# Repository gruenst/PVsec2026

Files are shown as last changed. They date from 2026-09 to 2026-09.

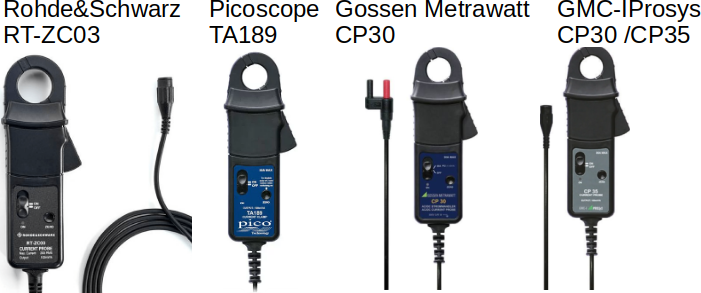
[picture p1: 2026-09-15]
02_CurrentClamp/ClampManufacturers.png

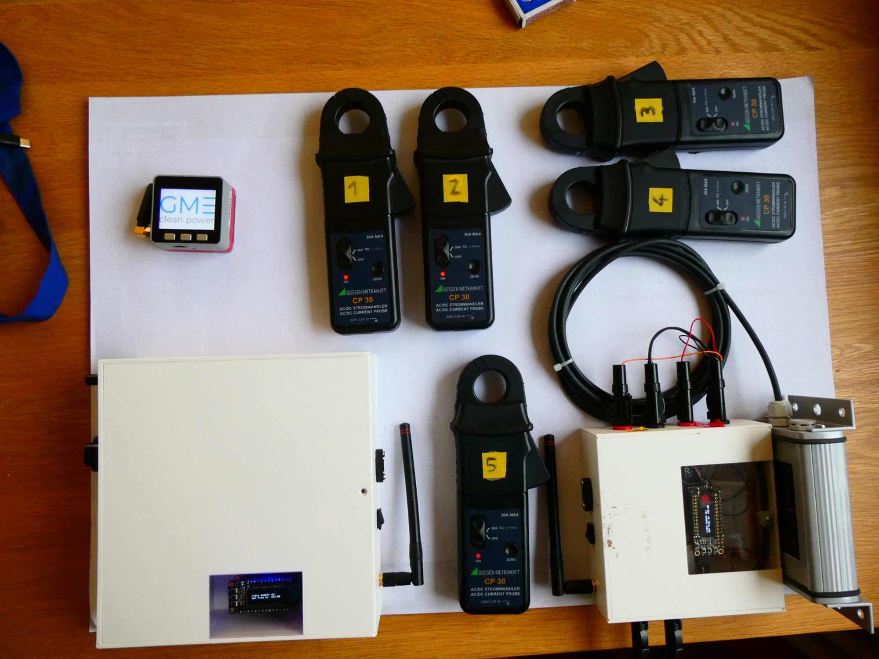
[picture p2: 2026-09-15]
03.JPG

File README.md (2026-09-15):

# Open Source Hardware for Mobile String Power Acquisition of Solar Parks
Circuitpython and C++ based measurement system for Photovoltaic Installations. Up to 10 current clamps can be integrated, additional voltage, current and module temperature acquisition.


## Purpose
 * Open-source enhancements of publicly available hardware resources with LoRa radio for long range sensor data acquisition capability (no mesh network).
 * Complete system for measuring solar parks with flawed or without string monitoring
 * Versatile alternative to IV curve acquisition systems specifically for systems without single string accessibility - adapt to your own liking.

## Usage
 * Plug device in, opens up as USB stick (circuitpython)
 * Open .html file in Web Serial API compatible browser (Chrome, Edge, Opera; see https://developer.mozilla.org/en-US/docs/Web/API/Serial)
 * Use browser as GUI, connect to device and send/receive commands to/from device via serial interface
 * commands will be forwarded via LoRa RFM98W radio chip to remote device
 
## Content
 - Descriptions:    Short descriptions of each system with pictures 
 - PCBs, BOM:       EAGLE Cad PCB files, list of components
 - Housing:         3D STP files for 3D printing
 - Circuit Python:  Circuitpython .uf2, device code
 - GUI:             code.py for device, .html code with .js elements for GUI control, Arduino C++ code, web Serial or WLAN websocket control
 - bootloader:      Atmel SAMD bootloader for JLink
[https://learn.adafruit.com/how-to-program-samd-bootloaders](https://learn.adafruit.com/how-to-program-samd-bootloaders)

## Manual
 - Make PCB, solder components
 - flash bootloader using .bin file, e.g. via JLink, see https://learn.adafruit.com/how-to-program-samd-bootloaders
 - mount device via usb, put into bootloader mode, upload circuitpython .uf2 file
 - copy circuitpython8 lib elements to /lib directory on device
 - put code.py to device
 - upload .html file to device, adjust accordingly
 enjoy!
 
[Grn.Solar](https://www.grn.solar)
 
 Big shoutouts to [Adafruit](https://www.adafruit.com "Adafruit rocks") and Flaticon.

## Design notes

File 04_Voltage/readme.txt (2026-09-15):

Lazy build for embedding a Phoenix Contact DC voltage level shifter (SCK-M-U-1500V) into a 3D printed case.
These components should be on the board:
 - 24V supply for the Phoenix Contact, power by 5V:  Murata NME0524DC
 - Adafruit ADS1115 breakout board
 - Adafruit PowerBoost 1000 Charger
 - Adafruit ItsyBitys M4 express
 
Embedding everything on a single PCB would be beneficial, but using an industry standard for 1500V string voltages seems reasonable.

DC connection via panel mount plugs (banana or solar connectors).
Power switch, with LED.
USB and SMA antenna plugs recommended.

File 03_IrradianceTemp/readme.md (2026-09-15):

# irradiance sensor with module temperature acquisition

Modification/hack of standard M&T irradiance sensors with an own-made PCB, and battery for independent operation.
As the current clamps, this is base don the Adafruit Itsybitsy M4 Express, so the code can be adapted/changed in the field with any computer (mounts as USB stick).
There is an USB B and C adapter for charging and programming.
There are soldering ports for adding a power switch, and adding an indicator LED. Alternatively, use a LED button.
PT temperature acquisition is done with a simple resistor bridge, as usually attachment of field sensors are by far the higher source of uncertainty than wire resistances.
But feel free to add a proper 4wire PT reading circuit (e.g. MAX31865), which was tested in yet another implementation.
As PT sensors, I recommend foil based ones with temperature conductive pastes. But whichever sensor, there is a lot to learn using them.

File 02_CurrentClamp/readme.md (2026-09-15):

# Current Clamp
resources for making a PCB for enhancing/hacking a commercially available DC current clamp (see type information) with LoRa and programming functionality. Here's a list of (probably identical) OEM products, only the third one has been used so far: ClampManufacturers

The board is based on the Adafruit "Itsybitsy M4 express" for Circuitpython, as this gives in-field programming capability (changing the current clamp number) with any USB computer. The PCB fits nicely underneath the existing PCB.
As an antenna, any flexible and solderable antenna for 433MHz works, also simple wire or spring antennas.
I recommend this one: https://ctrfantennasinc.com/flex-pcb-433mhz-lora-antenna/

Node numbers are 1-10 for the clamps, and 11-13 for the additional satellite systems (irradiance+temperature, voltage, repeater).

Instead of a standard 9V battery, a modified Li-based battery could be used and connected to the PCB for charging purpose.
Alternatively, add another battery or power bank for longer usage times.

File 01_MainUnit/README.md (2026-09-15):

# Main Unit
Either use an M5 Stack for control. Or use an USB LoRa adapter, plugged into your computer or smartphone.

- M5 Stack: can be controlled directly via buttons. Or via WLAN (webSocket) GUI.
- USB LoRa adapter:  dongle for LoRa communication, design based on Adafruit ItsyBitsy M4 Express. Can be controlled via USB (webSerial) or Android/iOS application (Flutter). Mounts as an USB stick with index.html accessible (Circuitpython).

NOTE:
M5 Stack fully works and was field tested.
USB LoRa adapter has not been tested. 
It's all there. But adaptations might be necessary.

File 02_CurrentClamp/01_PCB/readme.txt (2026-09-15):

EAGLE CAD files and BOM files for making current clamp modification PCB

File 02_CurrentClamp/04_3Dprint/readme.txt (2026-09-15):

3D printed case for replacing the entry cable hole of a Gossen Metrawatt CP30 current clamp with an USB connector
Originally designed for this connector:
https://www.adafruit.com/product/1829
..but really, anything works, if solderable..

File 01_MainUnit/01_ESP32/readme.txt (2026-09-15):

Easiest solution for the main unit:
The basic M5stack comes with an ESP32, display, SCcard slot and buttons.
https://shop.m5stack.com/products/esp32-basic-core-lot-development-kit-v2-7

In the meantime, there's also a LoRa 433MHz extension:
https://shop.m5stack.com/products/m5stack-lora-module-433mhz-v1-1
(adapt arduino code accordingly)

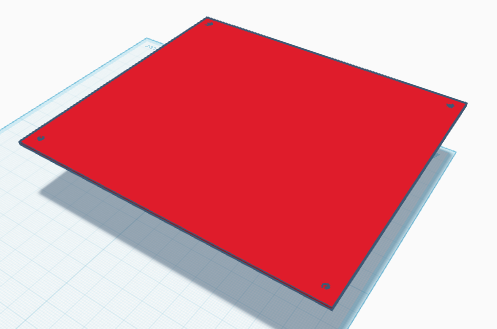
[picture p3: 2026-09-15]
04_Voltage/04_3Dprint/lid.png

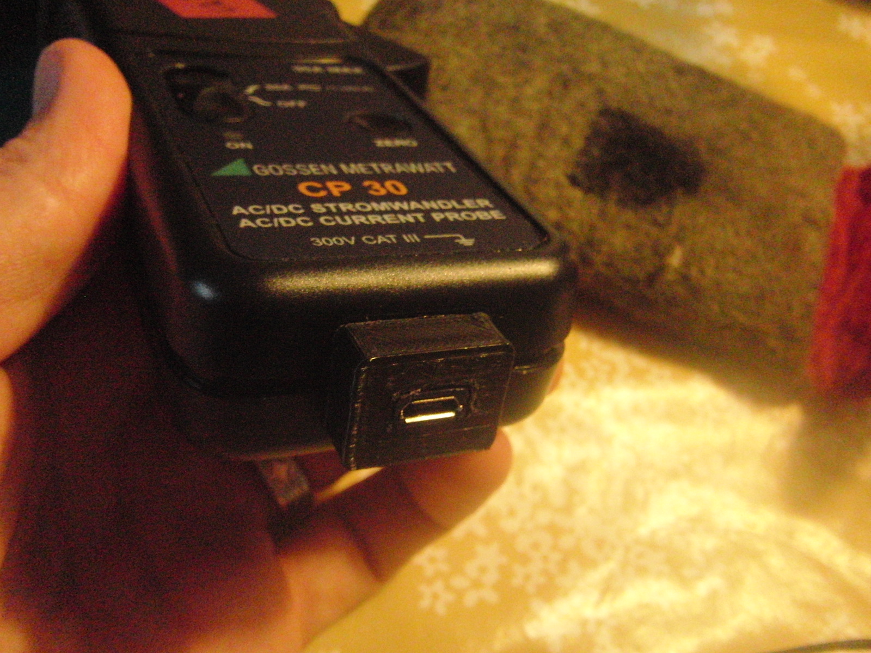
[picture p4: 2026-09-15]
02_CurrentClamp/05_images/CIMG1481.JPG

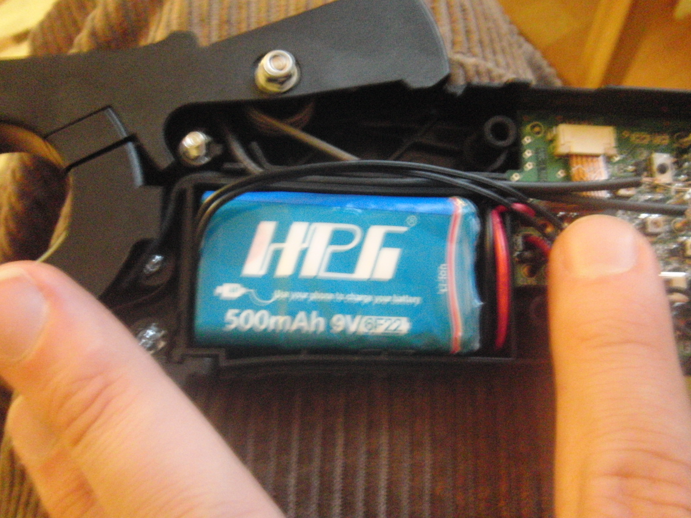
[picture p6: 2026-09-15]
02_CurrentClamp/05_images/CIMG1492.JPG

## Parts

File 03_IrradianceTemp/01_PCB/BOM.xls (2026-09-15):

Component | Description | size | form factor
C1 | 10.0µF, 0805 SMD Capacitor | 10uF | 805
C2 | 100.0nF, 0603 SMD Capacitor | 0.1uF | 603
C3 | 1.0µF, 0603 SMD Capacitor | 1uF | _0603MP
C4, C5, C7 | 1.0µF, 0603 SMD Capacitor | 1uF | 603
C6, C8, C10 | 10.0µF, 0805 SMD Capacitor | 10µF | 805
C9 | 10.0µF, 0805 SMD Capacitor | 10uF | _0805MP
D1 | MBR120AFC_R1_00001 https://www.panjit.com.tw/upload/datasheet/MBR18AFC_SERIES.pdfPANJIT | MBR120 | SOD123
FB1, FB2 | MMZ2012Y152BT000 https://product.tdk.com/en/system/files | MMZ2012Y152B | 805
IC2 | ATSAMD51G19A-MU https://www.mouser.com/datasheet/3/282/1/SAM_D5x_E5x_Family_Data_Sheet_DS60001507.pdfMicrochip | ATSAMD51G_TQFN48 | TQFN48_7MM
J1 | UJ2-MIBH-G-SMT-TR https://www.sameskydevices.com/product/resource/uj2-mibh-g-smt-tr.pdfSame Sky | UJ2-MIBH-G-SMT-TR | CUI_UJ2-MIBH-G-SMT-TR
L2 | 3341 Adafruit | RGB | APA102_2020
R1, R2, R5 | 10.0kΩ, 0805 SMD Resistor | 10K | 805
R3, R7 | 100.0kΩ, 0805 SMD Resistor | 100K | 805
R4 | 2.2kΩ, 0805 SMD Resistor | 2.2K | 805
R6 | 300.0Ω, 0805 SMD Resistor | 0.3K | 805
R8, R9 | 4.02kΩ, 0805 SMD, 1% Resistor | 4.02K | 805
R10 | 1.0kΩ, 0805 SMD Resistor | 1k | 805
R11 | 2.0kΩ, 0805 SMD Resistor | 2k | 805
R12, R13 | 5.1kΩ, 0805 SMD Resistor | 5.1K | 805
U1 | RFM98W-433S2 http://www.farnell.com/datasheets/1870822.pdfHoperf | RFM98-W | RFMHCW_SMT
U2 | INA219BIDCNT https://www.ti.com/lit/gpn/INA219Texas Instruments | INA219 | SOT23-8
U3 | AP2112K-3.3TRG1 https://www.diodes.com/assets/Datasheets/AP2112.pdfDiodes Inc. | AP2112K-3.3 | SOT23-5
U4 | GD25Q16CEIGR GigaDevice | GD25x16 | USON8
U5 | ADS1115IDGSR https://www.ti.com/lit/gpn/ADS1115Texas Instruments | ADS1115 | MSOP10
U6 | MCP73831T-2ACI/OT https://ww1.microchip.com/downloads/aemDocuments/documents/APID/ProductDocuments/DataSheets/MCP73831-Family-Data-Sheet-DS20001984H.pdfMicrochip | MCP73831T | SOT23-5
X1 | 1769 Adafruit | JSTPH | JSTPH2
X2 | 4458 Adafruit |  | USB_C_CUSB31-CFM2AX-01-X
U1 | HopeRF RFMHCW_SMT | RFM98-W

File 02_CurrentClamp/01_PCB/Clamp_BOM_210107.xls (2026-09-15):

Number | Manufacturer | Type | Package | description
1 | Texas Instruments | ADS1115 | VSSOP | 16bit ADC
1 | SHENZHEN LED COLOR | APA102 2020 | - | dotstar RGB LED
1 | Gigadevice | GD25Q16CEIGR | USON8 | SPI FLASH 8PIN
1 | HopeRF | RFM98W | RFMHCW_SMT | LoRa 433MHz
1 | Diodes Incorporated | AP2112K-3.3TRG1 | SOT23-5 | Voltage Regulator
2 | <any> | resistor 100k | 0805 | resistor 100k
2 | <any> | resistor 2.2k | 0805 | resistor 2.2k
3 | <any> | resistor 10k | 0805 | resistor 10k
2 | ON semiconductor | MBR120 | SOD-123FL | diode
1 | <any> | standard red LED SMD | 'CHIPLED 0603 | standard red LED SMD
1 | Microchip technology / atmel | ATSAMD51G19A | 48 QFN | SAM Microcontroller
2 | tdk | MMZ2012Y152B | 0805 | Ferrite Bead
4 | <any> | capacitor 10uF | 0805 | capacitor 10uF
4 | <any> | capacitor 1uF | 0603 | capacitor 1uF

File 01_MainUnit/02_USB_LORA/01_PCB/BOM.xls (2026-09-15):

Component | Description | size | form factor
C1 | 10.0µF, 0603 SMD Capacitor | 10uF | 0603@1
C2, C5, C7 | 1.0µF, 0603 SMD Capacitor | 1µF | 0603@1
C3, C4, C6 | 10.0µF, 0603 SMD Capacitor | 10µF | 0603@1
R1, R4 | 100.0kΩ, 0603 SMD Resistor | 100k | 603
R2, R3 | 5.1kΩ, 0603 SMD Resistor | 5.1k | 603
R6 | 10.0kΩ, 0805 SMD Resistor | 2.2K | 805
R7 | 10.0kΩ, 0805 SMD Resistor | 10K | 805
IC2 | ATSAMD51G19A-MU https://www.mouser.com/datasheet/3/282/1/SAM_D5x_E5x_Family_Data_Sheet_DS60001507.pdfMicrochip | ATSAMD51G_TQFN48 | TQFN48_7MM
L2 | 3341 Adafruit | RGB | APA102_2020
U3 | AP2112K-3.3TRG1 https://www.diodes.com/assets/Datasheets/AP2112.pdfDiodes Inc. | AP2112K-3.3 | SOT23-5
U4 | GD25Q16CEIGR GigaDevice | GD25x16 | USON8
USB_C | 4932 https://cdn-shop.adafruit.com/product-files/4932/Pinout+Diagram.pngAdafruit | USB_TYPE_C_12PUSB_TYPE_C_12P | USB_TYPE_C_12P
USB_C2 | 4458 Adafruit |  | USB_C_CUSB31-CFM2AX-01-X
U1 | HopeRF RFMHCW_SMT | RFM98-W

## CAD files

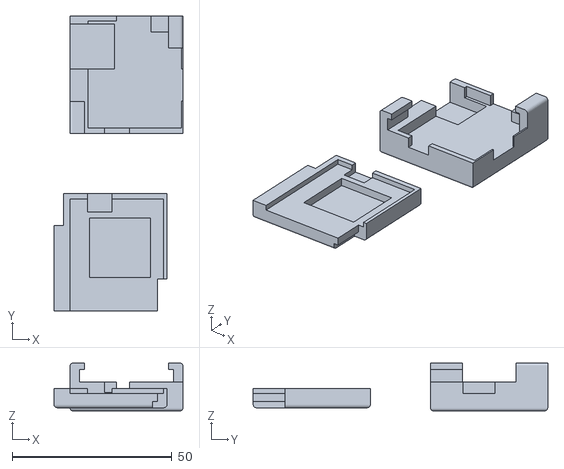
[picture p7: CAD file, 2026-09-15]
01_MainUnit/02_USB_LORA/04_3Dprint/USB_LoRa.stl
40.4 x 92.2 x 15.0

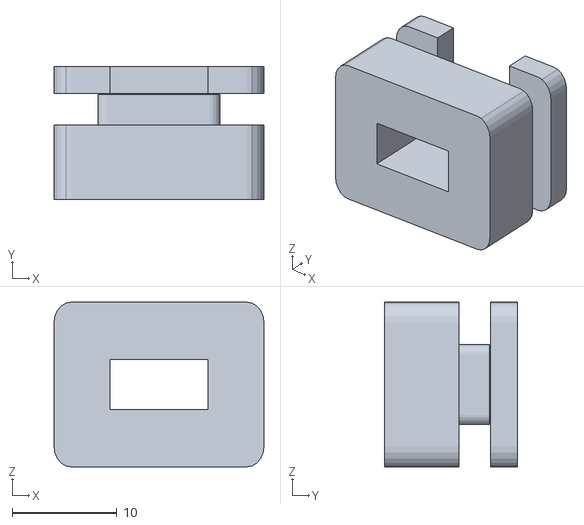
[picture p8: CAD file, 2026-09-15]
02_CurrentClamp/04_3Dprint/ClampHole_201114.stl
20.0 x 12.7 x 15.7

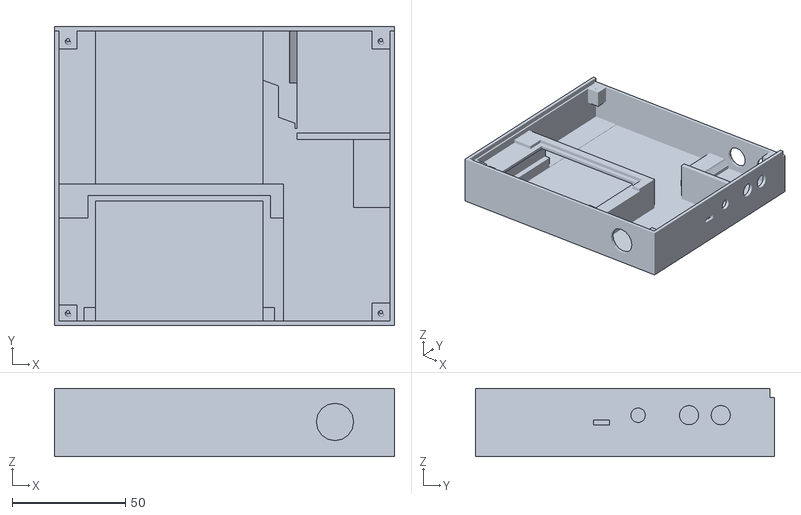
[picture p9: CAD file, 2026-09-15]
04_Voltage/04_3Dprint/box.stl
150.0 x 132.0 x 30.0

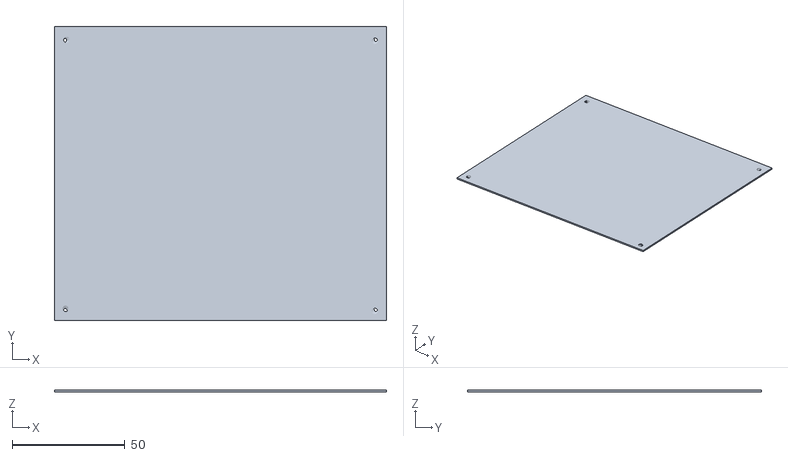
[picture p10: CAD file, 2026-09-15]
04_Voltage/04_3Dprint/lid.stl
147.5 x 130.7 x 0.9

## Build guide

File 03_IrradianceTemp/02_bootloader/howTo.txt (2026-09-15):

 After printing PCB:
 1) flash a basic bootloader on PCB using JLINK hardware, steps:
  - connect JLINK to PC and pins to PCB (1-voltage, 2-gnd, -1-IO -2-clk)
  - power PCB (Vref) with another arduino or DC voltage source
  - use command line from folder with .bin file
  - flash bootloader by executing software "JLinkExe"
  - select JLinkExe-options ('connect' -> ATSAMD51G19A - SWD -> default)
  - execute command 'loadbin Clamp_bootloader_260901.bin,0'
  - select JLinkExe-options ('r' -> 'g')
 2) get CircuitPython for "ItsyBitsy M4 Express", upload .uf2 to board
 https://circuitpython.org/board/itsybitsy_m4_express/
 3) upload circuitpython library bundle
 https://circuitpython.org/libraries
 4) upload code.py
 ...and modify to your own liking...

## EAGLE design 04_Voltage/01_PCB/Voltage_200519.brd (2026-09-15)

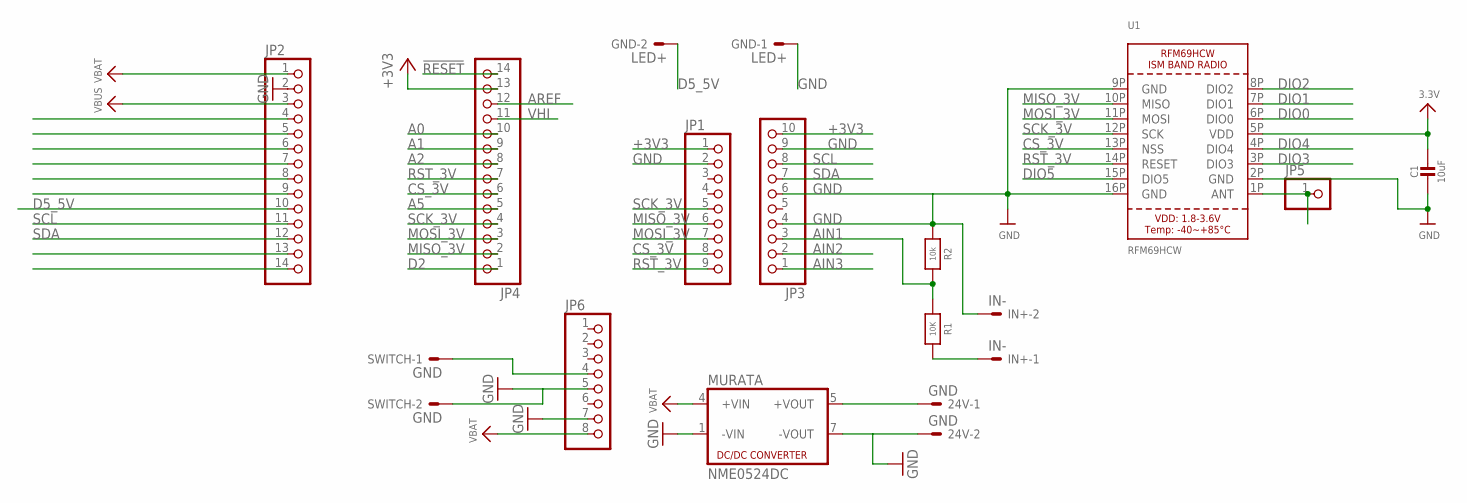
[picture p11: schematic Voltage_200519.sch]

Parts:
24V: GND; 332-02
C1: 10uF; 0805-NO@1
GND: LED+; 332-02
IN+: IN-; 332-02
JP1: HEADER-1X970MIL; 1X09_ROUND_70
JP2, JP4: HEADER-1X14; 1X14_ROUND70
JP3: HEADER-1X1070MIL; 1X10_ROUND70
JP5: HEADER-1X1ROUND; 1X01_ROUND
JP6: HEADER-1X8ROUND; 1X08_ROUND
MURATA: NME0524DC; 8DIL-4
R1: 10K; 0805-NO
R2: 10k; 0805-NO
SWITCH: GND; 332-02
U1: RFM69HCW; RFMHCW_SMT

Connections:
!RESET: JP4.14
+3V3: C1.1, JP1.1, JP3.10, JP4.13, U1.5P (VDD)
A0: JP4.10
A1: JP4.9
A2: JP4.8
A5: JP4.5
AIN1: JP3.3, R1.1, R2.2
AIN2: JP3.2
AIN3: JP3.1
AREF: JP4.12
CS_3V: JP1.8, JP4.6, U1.13P (NSS)
D2: JP4.1
D5_5V: GND.2, JP2.10
D7: JP2.9
D9: JP2.8
D10: JP2.7
D11: JP2.6
D12: JP2.5
D13: JP2.4
DIO0: U1.6P (DIO0)
DIO1: U1.7P (DIO1)
DIO2: U1.8P (DIO2)
DIO3: U1.3P (DIO3)
DIO4: U1.4P (DIO4)
DIO5: U1.15P (DIO5)
GND: 24V.2, C1.2, GND.1, IN+.2, JP1.2, JP2.2, JP3.4, JP3.6, JP3.9, JP6.5, JP6.7, MURATA.1 (-VIN), MURATA.7 (-VOUT), R2.1, SWITCH.2, U1.2P (GND), U1.9P (GND), U1.16P (GND)
MISO_3V: JP1.6, JP4.2, U1.10P (MISO)
MOSI_3V: JP1.7, JP4.3, U1.11P (MOSI)
unnamed: JP5.1, U1.1P (ANT)
unnamed: JP6.4, SWITCH.1
unnamed: IN+.1, R1.2
unnamed: 24V.1, MURATA.5 (+VOUT)
RST_3V: JP1.9, JP4.7, U1.14P (RESET)
RX_D0: JP2.14
SCK_3V: JP1.5, JP4.4, U1.12P (SCK)
SCL: JP2.11, JP3.8
SDA: JP2.12, JP3.7
TX_D1: JP2.13
VBAT: JP2.1, JP6.8, MURATA.4 (+VIN)
VBUS: JP2.3
VHI: JP4.11

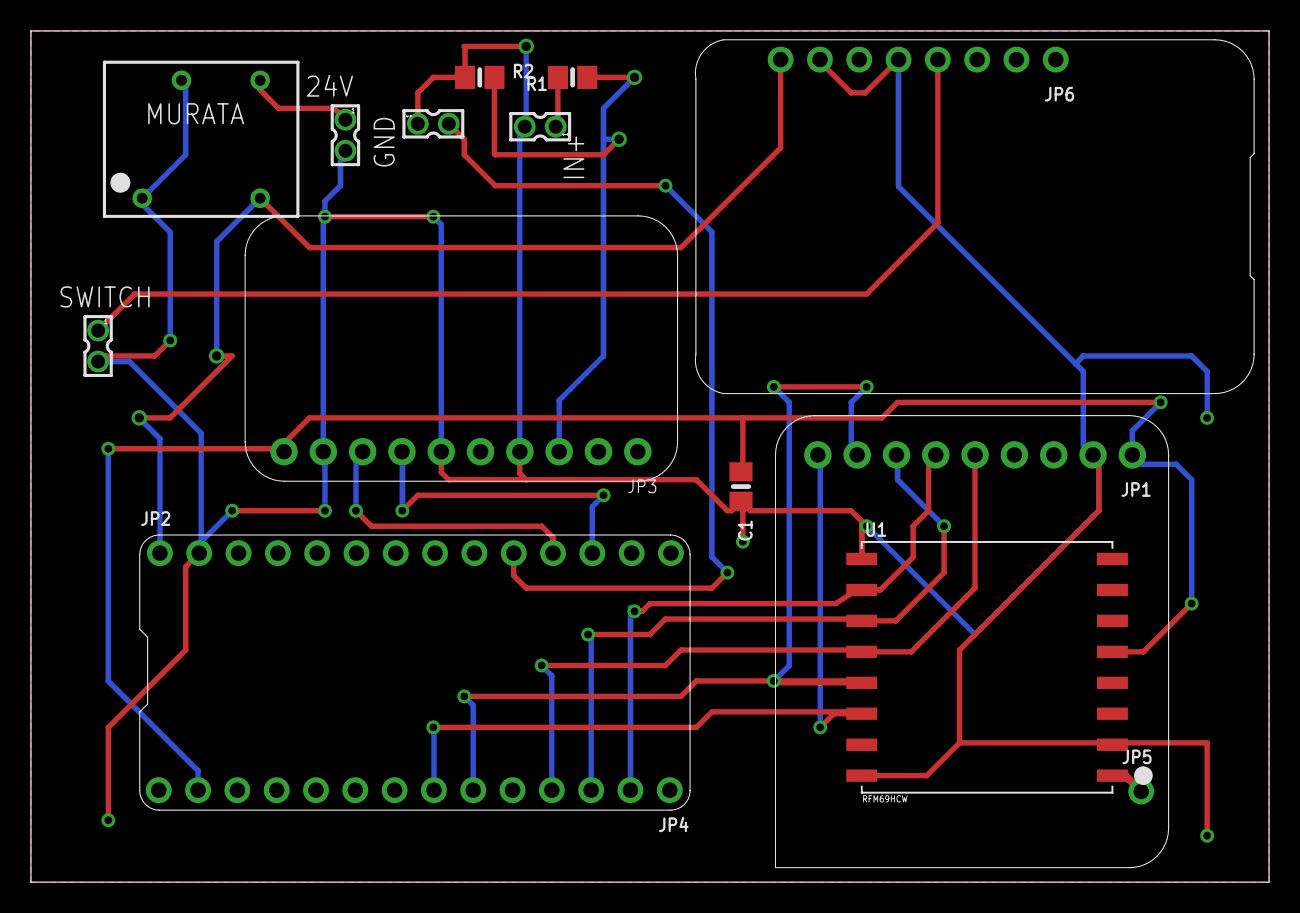
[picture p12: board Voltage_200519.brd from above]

Board: 2 copper layers, 80.0 x 55.0 mm, 15 parts (0 on the bottom side), 16 nets.

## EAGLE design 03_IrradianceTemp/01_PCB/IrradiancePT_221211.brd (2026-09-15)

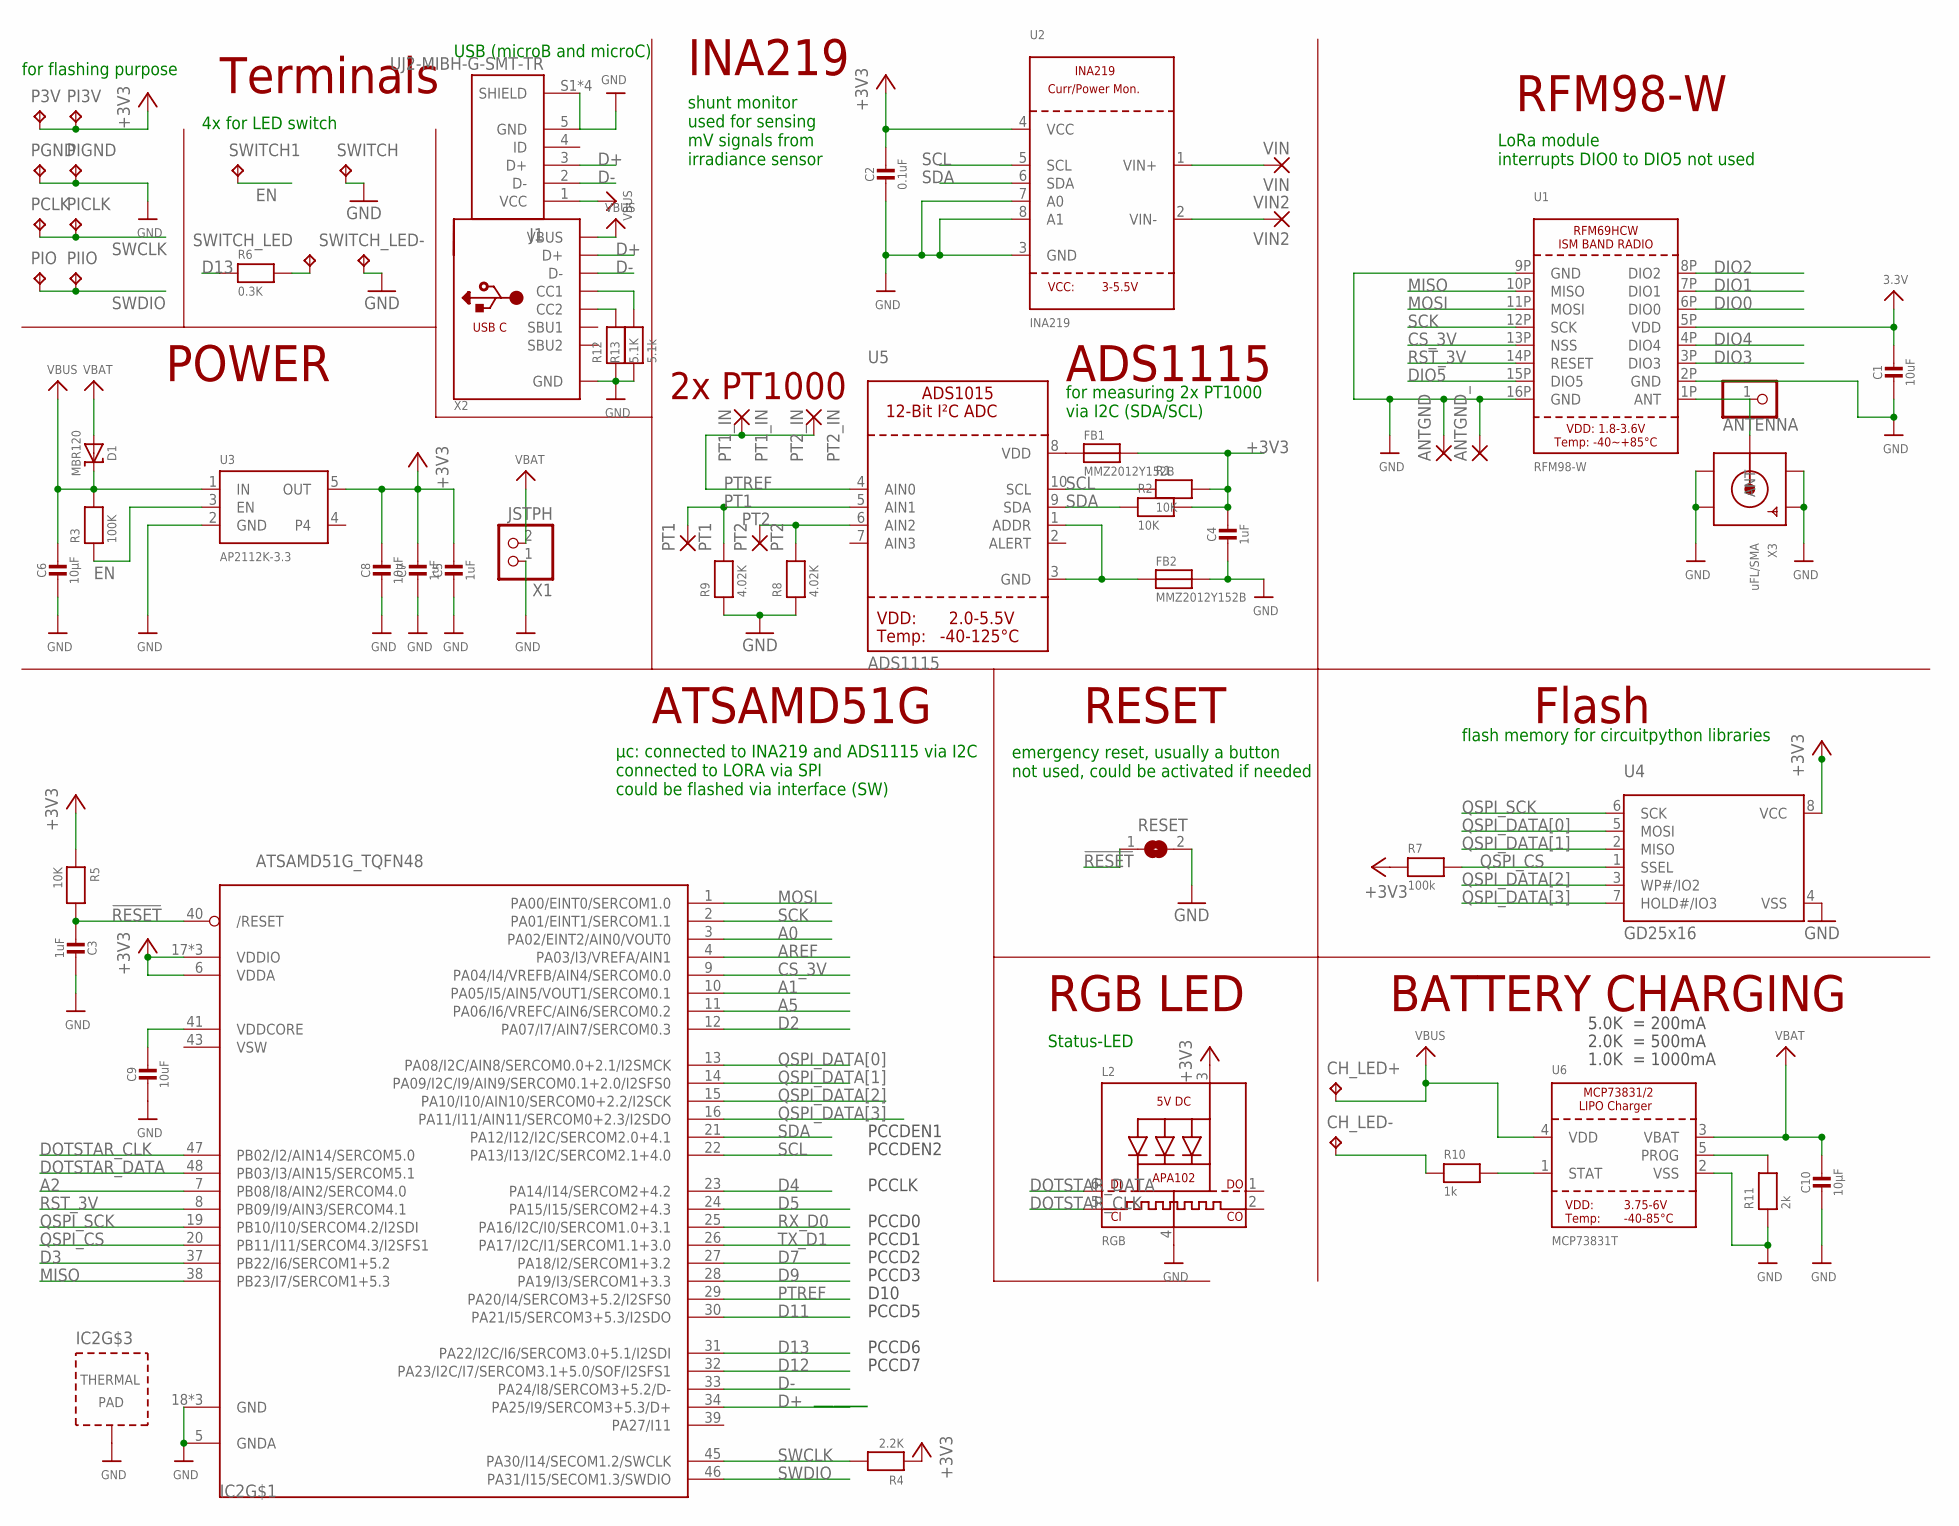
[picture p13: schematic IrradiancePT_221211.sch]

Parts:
ANTENNA: HEADER-1X1ROUND; 1X01_ROUND
ANTGND: SMD5; SMD2,54-5,08
ANTGND_: SMD5; SMD2,54-5,08
C1: 10uF; 0805-NO
C2: 0.1uF; 0603-NO
C3: 1uF; _0603MP
C4, C5, C7: 1uF; 0603-NO
C6, C8, C10: 10µF; 0805-NO
C9: 10uF; _0805MP
CH_LED+: TPPAD1-13; P1-13
CH_LED-: TPPAD1-13; P1-13
D1: MBR120; SOD-123
FB1, FB2: MMZ2012Y152B; 0805
IC2: ATSAMD51G_TQFN48; TQFN48_7MM
J1: UJ2-MIBH-G-SMT-TR; CUI_UJ2-MIBH-G-SMT-TR
L2: RGB; APA102_2020
P3V: TPTP20R; TP20R
PCLK: TPTP20R; TP20R
PGND: TPTP20R; TP20R
PI3V: TPPAD1-13; P1-13
PICLK: TPPAD1-13; P1-13
PIGND: TPPAD1-13; P1-13
PIIO: TPPAD1-13; P1-13
PIO: TP20R
PT1: PT1; 1,6/0,9
PT1_IN: PT1_IN; 1,6/0,9
PT2: PT2; 1,6/0,9
PT2_IN: PT2_IN; 1,6/0,9
R1, R2, R5: 10K; 0805
R3: 100K; 0805
R4: 2.2K; 0805
R6: 0.3K; 0805
R7: 100k; 0805
R8, R9: 4.02K; 0805
R10: 1k; 0805
R11: 2k; 0805
R12: 5.1K; 0805
R13: 5.1k; 0805
RESET: SOLDERJUMPER; SOLDERJUMPER_ARROW_NOPASTE
SWITCH, SWITCH1: TPPAD1-13; P1-13
SWITCH_LED: TPPAD1-13; P1-13
SWITCH_LED-: TPPAD1-13; P1-13
U1: RFM98-W; RFMHCW_SMT
U2: INA219; SOT23-8
U3: AP2112K-3.3; SOT23-5
U4: GD25x16; USON8
U5: ADS1115; MSOP10
U6: MCP73831T; SOT23-5
VIN: VIN; 1,6/0,9
VIN2: VIN2; 1,6/0,9
X1: JSTPH; JSTPH2
X2: USB_C; USB_C_CUSB31-CFM2AX-01-X
X3: uFL/SMA; SMA_EDGELAUNCH_UFL

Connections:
!RESET: C3.2, IC2.40 (/RESET), R5.2, RESET.1
+3V3: C1.1, C2.1, C4.1, C5.1, C7.1, C8.1, FB1.2, IC2.6 (VDDA), IC2.17 (VDDIO), IC2.36 (VDDIO), IC2.44 (VDDIO), L2.3 (VDD), P3V.TP, PI3V.TP, R1.2, R2.2, R4.1, R5.1, R7.1, U1.5P (VDD), U2.4 (VCC), U3.5 (OUT), U4.8 (VCC)
A0: IC2.3 (PA02/EINT2/AIN0/VOUT0)
A1: IC2.10 (PA05/I5/AIN5/VOUT1/SERCOM0.1)
A2: IC2.7 (PB08/I8/AIN2/SERCOM4.0)
A5: IC2.11 (PA06/I6/VREFC/AIN6/SERCOM0.2)
AREF: IC2.4 (PA03/I3/VREFA/AIN1)
CS_3V: IC2.9 (PA04/I4/VREFB/AIN4/SERCOM0.0), U1.13P (NSS)
D2: IC2.12 (PA07/I7/AIN7/SERCOM0.3)
D3: IC2.37 (PB22/I6/SERCOM1+5.2)
D4: IC2.23 (PA14/I14/SERCOM2+4.2)
D5: IC2.24 (PA15/I15/SERCOM2+4.3)
D7: IC2.27 (PA18/I2/SERCOM1+3.2)
D9: IC2.28 (PA19/I3/SERCOM1+3.3)
D11: IC2.30 (PA21/I5/SERCOM3+5.3/I2SDO)
D12: IC2.32 (PA23/I2C/I7/SERCOM3.1+5.0/SOF/I2SFS1)
D13: IC2.31 (PA22/I2C/I6/SERCOM3.0+5.1/I2SDI), R6.1
D+: IC2.34 (PA25/I9/SERCOM3+5.3/D+), J1.3 (D+), X2.A6 (D+), X2.B6 (D+)
D-: IC2.33 (PA24/I8/SERCOM3+5.2/D-), J1.2 (D-), X2.A7 (D-), X2.B7 (D-)
DIO0: U1.6P (DIO0)
DIO1: U1.7P (DIO1)
DIO2: U1.8P (DIO2)
DIO3: U1.3P (DIO3)
DIO4: U1.4P (DIO4)
DIO5: U1.15P (DIO5)
DOTSTAR_CLK: IC2.47 (PB02/I2/AIN14/SERCOM5.0), L2.5 (CKI)
DOTSTAR_DATA: IC2.48 (PB03/I3/AIN15/SERCOM5.1), L2.6 (DI)
EN: R3.1, SWITCH1.TP, U3.3 (EN)
GND: ANTGND.1, ANTGND_.1, C1.2, C2.2, C3.1, C4.2, C5.2, C6.2, C7.2, C8.2, C9.2, C10.2, FB2.2, IC2.5 (GNDA), IC2.18 (GND), IC2.35 (GND), IC2.42 (GND), IC2.THERMAL (TP), J1.5 (GND), J1.S1 (SHIELD), J1.S2 (SHIELD), J1.S3 (SHIELD), J1.S4 (SHIELD), L2.4 (GND), PGND.TP, PIGND.TP, R8.1, R9.1, R11.1, R12.1, R13.1, RESET.2, SWITCH.TP, SWITCH_LED-.TP, U1.2P (GND), U1.9P (GND), U1.16P (GND), U2.3 (GND), U2.7 (A0), U2.8 (A1), U3.2 (GND), U4.4 (VSS), U6.2 (VSS), X1.1, X2.A1B12 (GND), X2.B1A12 (GND), X3.GND@1 (GND1), X3.GND@2 (GND2), X3.GND@3 (GND3), X3.GND@4 (GND4)
GND_IN: FB2.1, U5.1 (ADDR), U5.3 (GND)
MISO: IC2.38 (PB23/I7/SERCOM1+5.3), U1.10P (MISO)
MOSI: IC2.1 (PA00/EINT0/SERCOM1.0), U1.11P (MOSI)
unnamed: ANTENNA.1, U1.1P (ANT), X3.P (ANT)
unnamed: R6.2, SWITCH_LED.TP
unnamed: U2.1 (VIN+), VIN.1
unnamed: U2.2 (VIN-), VIN2.1
unnamed: FB1.1, U5.8 (VDD)
unnamed: CH_LED-.TP, R10.1
unnamed: R10.2, U6.1 (STAT)
unnamed: R11.2, U6.5 (PROG)
unnamed: R13.2, X2.A5 (CC1)
unnamed: R12.2, X2.B5 (CC2)
PT1: PT1.1, R9.2, U5.5 (AIN1)
PT2: PT2.1, R8.2, U5.6 (AIN2)
PTREF: IC2.29 (PA20/I4/SERCOM3+5.2/I2SFS0), PT1_IN.1, PT2_IN.1, U5.4 (AIN0)
QSPI_CS: IC2.20 (PB11/I11/SERCOM4.3/I2SFS1), R7.2, U4.1 (SSEL)
QSPI_DATA[0]: IC2.13 (PA08/I2C/AIN8/SERCOM0.0+2.1/I2SMCK), U4.5 (MOSI)
QSPI_DATA[1]: IC2.14 (PA09/I2C/I9/AIN9/SERCOM0.1+2.0/I2SFS0), U4.2 (MISO)
QSPI_DATA[2]: IC2.15 (PA10/I10/AIN10/SERCOM0+2.2/I2SCK), U4.3 (WP#/IO2)
QSPI_DATA[3]: IC2.16 (PA11/I11/AIN11/SERCOM0+2.3/I2SDO), U4.7 (HOLD#/IO3)
QSPI_SCK: IC2.19 (PB10/I10/SERCOM4.2/I2SDI), U4.6 (SCK)
RST_3V: IC2.8 (PB09/I9/AIN3/SERCOM4.1), U1.14P (RESET)
RX_D0: IC2.25 (PA16/I2C/I0/SERCOM1.0+3.1)
SCK: IC2.2 (PA01/EINT1/SERCOM1.1), U1.12P (SCK)
SCL: IC2.22 (PA13/I13/I2C/SERCOM2.1+4.0), R1.1, U2.5 (SCL), U5.10 (SCL)
SDA: IC2.21 (PA12/I12/I2C/SERCOM2.0+4.1), R2.1, U2.6 (SDA), U5.9 (SDA)
SWCLK: IC2.45 (PA30/I14/SECOM1.2/SWCLK), PCLK.TP, PICLK.TP, R4.2
SWDIO: IC2.46 (PA31/I15/SECOM1.3/SWDIO), PIIO.TP, PIO.TP
TX_D1: IC2.26 (PA17/I2C/I1/SERCOM1.1+3.0)
VBAT: C10.1, D1.A, U6.3 (VBAT), X1.2
VBUS: C6.1, CH_LED+.TP, D1.C, J1.1 (VCC), R3.2, U3.1 (IN), U6.4 (VDD), X2.A4B9 (VBUS), X2.B4A9 (VBUS)
VDDCORE: C9.1, IC2.41 (VDDCORE)
VSW: IC2.43 (VSW)

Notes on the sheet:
Terminals
RFM98-W
INA219
POWER
RESET
µc: connected to INA219 and ADS1115 via I2C connected to LORA via SPI could be flashed via interface (SW)
PCCDEN1
PCCDEN2
PCCD0
PCCD1
PCCD2
PCCD3
D10
PCCD5
PCCD6
PCCD7
PCCLK
Flash
RGB LED
ATSAMD51G
LoRa module interrupts DIO0 to DIO5 not used
shunt monitor used for sensing mV signals from irradiance sensor
emergency reset, usually a button not used, could be activated if needed
flash memory for circuitpython libraries
ADS1115
2x PT1000
Status-LED
for flashing purpose
USB (microB and microC)
for measuring 2x PT1000 via I2C (SDA/SCL)
5.0K = 200mA
2.0K = 500mA
1.0K = 1000mA
BATTERY CHARGING
4x for LED switch

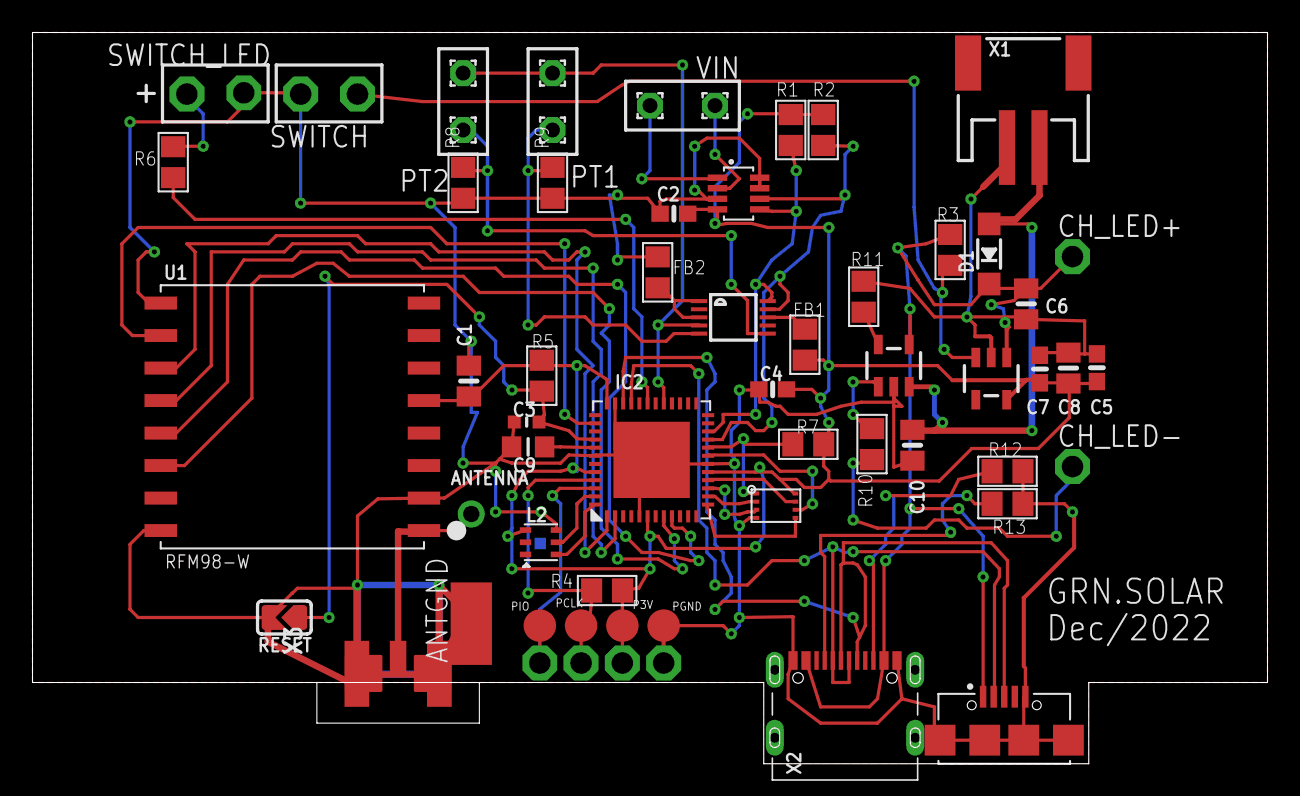
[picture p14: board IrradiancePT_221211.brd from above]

Board: 2 copper layers, 76.0 x 45.0 mm, 62 parts (1 on the bottom side), 41 nets.

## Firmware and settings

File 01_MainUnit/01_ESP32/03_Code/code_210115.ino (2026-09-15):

// Main Unit: receive measured data from satellite devices, central node point
// consists of: microcontroller (M5stack), LoRa Radio card (RFM96), RealTime Clock (DS1307)
// The M5stack contains: LiPo battery charging, microSD Card slot, WiFi interface, TFT display and 3 buttons
// function: 2 buttons for entering identifier; one button for measurement (2nd press stores data on SD card)
//           pressing the measurement button will trigger radio signal "measure" being sent; data will then be collected
//           from every satellite device individually
// The M5stack opens up a webserver at startup; when connecting via WiFi, data can be sent both way via the websocket; simply open IP in browser.
// Code Structure:  <libraries/definitions>  <setup>  <code loop>

//----------- Libraries -------------------------------------
#include <SPI.h>
//#include <RHGenericSPI.h>
//#include <RH_RF95.h>
#include <M5LoRa.h>
#include <Wire.h>
#include <SD.h>  //not needed with M5?
#include <M5Stack.h>
#include <WiFi.h>
#include <ESPAsyncWebServer.h>
#include <SPIFFS.h>
#include "RTClib.h"
//--------END Libraries -------------------------------------

//-----------PIN definitions---------------------------------
#define RFM95_CS 5       // LoRa Chip Select
#define RFM95_RST 35     // LoRa Reset pin   //36 on first M5!!!
#define RFM95_INT 26     // LoRa Interrupt pin
//-------END PIN definitions---------------------------------

//-------Global variables, drivers and definitions -----------
#define RF95_FREQ 433E6  //LoRa frequency
#define NUM_SATELLITES 13   // number of satellite devices, followed by the keywords for each one
String satellites[NUM_SATELLITES] = {"clamp_1", "clamp_2", "clamp_3", "clamp_4", "clamp_5","clamp_6", "clamp_7", "clamp_8", "clamp_9", "clamp_0", "irr_1", "volt_1","irr_2"};
//String satellites[NUM_SATELLITES] = {"clamp_1", "clamp_2", "clamp_3", "clamp_4", "irr_1", "volt_1","irr_2"};
String answers[NUM_SATELLITES]; // the answer strings with the measurement variables will be stored here
uint8_t Cursor = 0;             // cursor position
uint8_t NumClamps = 5;             // Number of Clamps 
uint64_t TriggerTime = 0;
String StringList = "-0123456789ABCDEFGHI";  // allowed characters for button character cycling
String StringID = "A-B-C-10-2";  //global var for string identifier
bool Saved = false;         // prevents from saving the same result multiple times   
bool FirstTime = true;   // writing the header to the SD card is only done once at the first SAVE operation
bool TftReset = true;       // TFT is cleared after measurement, not when changing string characters
bool ClampsOnly = false;
const char* SSID = "MAIN"; 
const char* PASSWORD = "testpass";
bool TriggerMeasure = false;      // measurement triggered from WLAN interface instead of button press
bool TriggerSave = false;        // save to file triggered from WLAN interface instead of button press
bool SaveToFile = false;       // choose to actually save to file
DateTime Now;          // time object
RTC_DS1307 rtc;        // real time clock
File MyFile;                // SD card file name
//---END Global variables, drivers and definitions -----------


//-------- Webserver and Websocket --------------------------
AsyncWebServer server(80);       // async web server on port 80
AsyncWebSocket ws("/ws");        // web socket is attached to server
AsyncWebSocketClient * GlobalClient = NULL;   // global client variable
// interrupt definitions for the websocket: gets activated by client
void onWsEvent(AsyncWebSocket * server, AsyncWebSocketClient * client, AwsEventType type, void * arg, uint8_t *data, size_t len){
  if(type == WS_EVT_CONNECT) GlobalClient = client; 
  else if(type == WS_EVT_DISCONNECT) GlobalClient = NULL;
  else if(type == WS_EVT_DATA)   // if a message from the client is received (MEASURE, CLAMPS, SAVE, TIME, or DATA)
  {
    String message = "";
    for(int i=0; i < len; i++)  message += char(data[i]);  // convert input characters to message-string
    if ((message.indexOf("MEASURE_") > -1) or (message.indexOf("CLAMPS_") > -1))    // used for starting the measurement
    {  TriggerMeasure = true;  SaveToFile = false;   // also aborts the data before saving
       if (message.indexOf("CLAMPS_") > -1) ClampsOnly  = true;
       else ClampsOnly = false;
       NumClamps = message[message.indexOf("_") + 1] - '0';  // simple convert character to integer
       if (NumClamps == 0) NumClamps = 10;   //  0 stands for 10
       StringID = message.substring(message.indexOf(';')+1,message.length());}   // read out string ID after ';'     
    else if (message.indexOf("SAVE") > -1) {  TriggerSave = true; SaveToFile = true; // save data to SD card
       StringID = message.substring(message.indexOf(';')+1,message.length());}
       
    else if (message.indexOf("TIME") > -1) {    // receive time string from websocket client
      message = message.substring(message.indexOf(';')+1,message.length());  
      M5.Lcd.println();M5.Lcd.println("time set");
      uint8_t dtDay, dtMonth, dtYear, dtHour, dtMinute;
      dtDay = message.substring(0,3).toInt();   
      dtMonth = message.substring(3,5).toInt(); 
      dtYear = message.substring(6,8).toInt();
      dtHour = message.substring(9,11).toInt();
      dtMinute = message.substring(12,14).toInt();
      rtc.adjust(DateTime(dtYear, dtMonth, dtDay, dtHour, dtMinute, 0));
      delay(500); 
      TftReset=true; 
    }
    else if (message.indexOf("DATA") > -1) {     // triggers all saved data from SD card being transferred back
      if (SD.exists("/AA_log.txt")) {
        MyFile = SD.open("/AA_log.txt", FILE_READ);
        String textLine = "DATA";
        if(GlobalClient != NULL && GlobalClient->status() == WS_CONNECTED)   //send file content via websocket
        {     
          while (MyFile.available())
          {
            char c = MyFile.read();
            textLine += c;
            if (c == '\n') {
              if (GlobalClient != NULL && GlobalClient->status() == WS_CONNECTED) GlobalClient->text(textLine);
              textLine = "DATA";
            }
          }
        }
        MyFile.close();
      }
    }
  }
}
//-------- END Webserver and Websocket --------------------------



void setup()    // initialize components, startup screen with logo
{
  //start M5stack without SD-Card and Serial;  SD-card is initialized further below
  M5.begin(true,false,false,true);   // LCD and I2C enable
  M5.Power.begin();  //start power management with charging
  //*****STARTUP SCREEN TEST, tests all components; halts if LoRa is not working
  M5.Lcd.fillScreen(TFT_BLACK);
  M5.Lcd.setRotation(1);
  M5.Lcd.setCursor(0, 0);
  M5.Lcd.setTextColor(TFT_WHITE);
  M5.Lcd.setTextSize(2);
  M5.Lcd.println("TFT:    OK");  // "if you see this, it works"
  
  M5.Lcd.print("Time: ");
  if (! rtc.begin())  M5.Lcd.println("failed");
  if (! rtc.isrunning())  rtc.adjust(DateTime(F(__DATE__), F(__TIME__)));   // adjust time when compiling code
  if (rtc.begin()) 
  { 
    Now = rtc.now();
    char tempString[20];
    sprintf(tempString, "%02d.%02d.%04d %02d:%02d", Now.day(), Now.month(), Now.year(), Now.hour(), Now.minute());
    M5.Lcd.println(tempString);
  } 
  //LoRa radio initialization
  LoRa.setPins(RFM95_CS, RFM95_RST, RFM95_INT);
  LoRa.setSpreadingFactor(9);
  LoRa.setSignalBandwidth(625E2);
  LoRa.setCodingRate4(8);
  LoRa.enableCrc();
  LoRa.setSPIFrequency(1E6);
  LoRa.setPreambleLength(8);
  //LoRa.setSyncWord(0x12);
  LoRa.setTxPower(23);
  //digitalWrite(RFM95_RST, LOW); delay(100); digitalWrite(RFM95_RST, HIGH); delay(5); // manual reset of LoRa chip
  M5.Lcd.print("Radio: ");
  if (!LoRa.begin(RF95_FREQ)) { M5.Lcd.println("failed"); while (1);  }  // HALTS if LoRa fails
  M5.Lcd.println("OK");
  LoRa.setSpreadingFactor(9);
  LoRa.setSignalBandwidth(625E2);
  LoRa.setCodingRate4(8);
  LoRa.enableCrc();
  LoRa.setSPIFrequency(1E6);
  LoRa.setPreambleLength(8);
  LoRa.setSyncWord(0x12);
  LoRa.setTxPower(23);
  M5.Lcd.print("frequ. ");
  M5.Lcd.print(RF95_FREQ/1000000,0);M5.Lcd.println("MHz");
  // SPIFFS initialization
  M5.Lcd.print("SPIFFS: ");
  if (!SPIFFS.begin(true)) M5.Lcd.println(" failed");
  else M5.Lcd.println("OK");
  // WiFi server initialization; async web server with web socket for two-way communication
  WiFi.softAP(SSID, PASSWORD);
  M5.Lcd.print("IP Adresse: ");
  M5.Lcd.println(WiFi.softAPIP());
  ws.onEvent(onWsEvent);
  server.addHandler(&ws);
  server.on("/", HTTP_GET, [](AsyncWebServerRequest* request) { request->send(SPIFFS, "/index.html");  } );
  server.begin();
  /*
  rf95.setTxPower(23, false);  //setIP LoRa radio boost to 23dB / 20dB(M5)
  rf95.setSignalBandwidth(125000);
  rf95.setCodingRate4(8);
  rf95.setPayloadCRC(true);
  */
  //begin SD card 
  M5.Lcd.print("SD card:  ");
  if (!SD.begin(4)) M5.Lcd.println("failed");
  else M5.Lcd.println("OK");
  delay(2000);
  //*****end startup screen
  //Startup Logo
  if (SD.exists("/logoTFT.png")) {M5.Lcd.drawPngFile(SD, "/logoTFT.png");
  delay(1500);}    // logo shown for 1.5 second
  //if possible get string name from TXT file  
  if (SD.exists("/string.txt"))
  {
    MyFile = SD.open("/string.txt");
    if (MyFile)
    {
      StringID = "";
      while (MyFile.available())
      {
        char x = MyFile.read();
        if (isGraph(x)) StringID.concat(x);  //only valid characters which make sense
      }
      MyFile.close();
    }
  }
  M5.update();
  delay(1000);
}


void loop()
{
  //********* BUTTON A AND B: CHANGE STRING IDENTIFIER
  if (TftReset == true)  // usually only renew characters without screen clearance
  {
    M5.Lcd.fillScreen(TFT_BLACK);M5.update();
    TftReset = false;
  }
  if (M5.BtnA.isPressed()) {
    if (Cursor == StringID.length() - 1) Cursor = 0;
    else Cursor += 1;
  }
  if (M5.BtnB.isPressed()) {
    uint16_t charIndex = StringList.indexOf(StringID.charAt(Cursor));
    if (charIndex == StringList.length() - 1) charIndex = 0;
    else charIndex += 1;
    StringID.setCharAt(Cursor, StringList.charAt(charIndex));
  }
  M5.Lcd.setCursor(0, 0);
  M5.Lcd.setTextSize(3);
  for (uint16_t i = 0; i < StringID.length(); i++)
  {
    if (i == Cursor) M5.Lcd.setTextColor(TFT_BLACK, TFT_WHITE);
    else M5.Lcd.setTextColor(TFT_WHITE, TFT_BLACK);
    M5.Lcd.print(StringID.charAt(i));
  }
  if (M5.BtnA.isPressed()) delay(200);  // faster cycling for character position
  if (M5.BtnB.isPressed()) delay(130);  // faster cycling for character change
  M5.update();
  GlobalClient->status();  // test: hopefully solves idling at first connection


  //*********MEASUREMENT BUTTON or CLIENT COMMAND MEASURE VIA WEBSOCKET
  if (M5.BtnC.wasPressed() or TriggerMeasure)
  {
    TriggerMeasure = false;
    TriggerSave = false;
    //server.reset();
    M5.Lcd.fillScreen(TFT_BLACK);
    M5.Lcd.setCursor(0, 0);
    M5.Lcd.setTextSize(2);
    M5.Lcd.setTextColor(TFT_WHITE, TFT_BLACK);
    M5.Lcd.println("measure...");
    M5.update();
    Now = rtc.now();  //RTC
    //-----------LoRa sequence, getting measurement data from satellites -------------------
    String command, numClamps;  // construct measurement command: "CL" for clamps only, or "ME" for all satellites, + clamp number
    if (NumClamps == 10) numClamps = '0';
    else numClamps = String(NumClamps);
    if (ClampsOnly) command = "CL"+numClamps;
    else  command = "ME"+numClamps;
    
    uint64_t startTime;
    for (uint8_t i = 0; i < 1; i++) //send command 1 time, second time by repeater
    {
      LoRa.beginPacket();
      LoRa.write(0x00);  //destination
      LoRa.write(0x00);  //source
      LoRa.write(0x00);  //MessageCount
      LoRa.write(command.length());
      LoRa.print(command);
      LoRa.endPacket();
      //delay(10);
      if (i==0) startTime = millis();
     }
    M5.Lcd.print("received ");
    for (uint8_t i = 0; i < NUM_SATELLITES; i++)  answers[i] = "";   // clear answers, in case of reception error
    bool allReceived = false;
    uint64_t maxTime = 0;
    if (ClampsOnly) maxTime = (NumClamps+1)*800;
    else  maxTime = (NUM_SATELLITES-10+NumClamps+2)*800;
    while ( (millis() - startTime < maxTime))  // max. 0.8s reading of responses from satellites
    {                                              
      if (LoRa.parsePacket() > 0)
      {
        byte messageLength, source;
        String message = "";
        for (uint8_t k=0; k<2; k++) source = LoRa.read();  // dump destination, use source;
        for (uint8_t k=0; k<2; k++) messageLength = LoRa.read();  // dump messageCount, messageLength not used
        while (LoRa.available()) {
          message += (char)LoRa.read();
        }
        if (message.startsWith(satellites[int(source)-1]))   //message starts with keyword
        {
          if (message.startsWith("irr_2"))       //special part for repeater unit! save repeated messages
          {
            while (message.indexOf("#") > 0)    //read out all extra messages
            {
              String repeatedAnswer = message.substring(message.lastIndexOf("#")+1);
              for (uint8_t j=0; j<NUM_SATELLITES; j++)
              {
                if (repeatedAnswer.startsWith(satellites[j]) )
                {
                  answers[j] = repeatedAnswer.substring(repeatedAnswer.indexOf(";")+1,repeatedAnswer.lastIndexOf(";")+1);  //strip identifier
                  M5.Lcd.print(j + 1);
                  j=NUM_SATELLITES; // breaks loop
                }
              }
              message = message.substring(0,message.lastIndexOf("#"));  //strip extra content from original message
            }
            startTime = 0;  // last message of repeater unit, breaks reception loop
          }   // end special part for repeater unit to save extra messages
            
          if (answers[int(source)-1] == "")  // only save one result
          {
            answers[int(source)-1] = message.substring(message.indexOf(";")+1,message.lastIndexOf(";")+1);  //strip identifier from message
            M5.Lcd.print(int(source)-1 + 1);
          }
        }
      }
    }
    //-----------END LoRa sequence, getting measurement data from satellites -------------------

    //-----------print results to TFT -------------------
    M5.Lcd.fillScreen(TFT_BLACK);
    M5.Lcd.setCursor(0, 0);
    M5.Lcd.println("Results:");
    M5.Lcd.setTextSize(2);
    for (uint8_t i = 0; i < NUM_SATELLITES; i++)
    {
      if (answers[i].length() < 1) {M5.Lcd.setTextColor(TFT_RED, TFT_BLACK); M5.Lcd.println("---");M5.Lcd.setTextColor(TFT_WHITE, TFT_BLACK);}
      for (uint8_t j = 0; j < answers[i].length(); j++)
      {
        if (answers[i].charAt(j) == ';') M5.Lcd.print('|');
        else M5.Lcd.print(answers[i].charAt(j));
        if (j == answers[i].length() - 1) M5.Lcd.println();
      }
    }
    //-----------END print results to TFT -------------------

    //-----------send results to client via web socket -------------------
    //test sequence, ONLY FOR TESTING/DEBUGGING
    //answers[0] = "1.2";answers[1]="3.2";answers[2]="4.3";answers[3]="4.3";answers[4]="8.4";answers[5]="800.0;-255.0;24.5;";answers[6]="600.0";answers[7]="323.2";
    if(GlobalClient != NULL && GlobalClient->status() == WS_CONNECTED)
    {
      char tempString[20];
      sprintf(tempString, "%02d.%02d.%04d %02d:%02d", Now.day(), Now.month(), Now.year(), Now.hour(), Now.minute());      
      String htmlString = "string;" + StringID + '|';
      htmlString += "time;" + String(tempString) + '|';
      for (uint8_t i = 0; i < NUM_SATELLITES; i++)
      {
        htmlString += satellites[i] + ';';
        if (answers[i].length() < 1) { if (satellites[i]=="irr_1") htmlString += "|tmod_1;|tmod_2;|"; else htmlString += '|';}
        else
        {
          if (satellites[i] == "irr_1") 
          {
            htmlString += String(answers[i].substring(0, answers[i].indexOf(";"))) + '|';
            htmlString += String("tmod_1") + ';';
            htmlString += String(answers[i].substring(answers[i].indexOf(";")+1, answers[i].indexOf(";",answers[i].indexOf(";")+1))) + '|';
            htmlString += String("tmod_2") + ';';
            htmlString += String(answers[i].substring(answers[i].indexOf(";",answers[i].indexOf(";")+1)+1, answers[i].lastIndexOf(";"))) + '|';
          }
          else htmlString += answers[i].substring(0, answers[i].indexOf(";")) + '|';
        }
      }
      GlobalClient->text(htmlString);
    }
    //-----------END send results to client via web socket -------------------

    //-----------save string identifier, wait for command to save results ------
    TftReset = true;
    Saved = false;
    //SD.remove("/string.txt"); //not needed with M5stack
    MyFile = SD.open("/string.txt", FILE_WRITE);
    MyFile.print(StringID);
    MyFile.close();
    while (not(M5.BtnA.isPressed() or M5.BtnC.wasPressed() or TriggerSave or TriggerMeasure)) {M5.update();}  //loop forever until further command
    if (M5.BtnA.isPressed() or TriggerMeasure) SaveToFile = false;   // do not save to SD card
    else SaveToFile = true;  //save to SD card
    TriggerSave = false;
    //-----------END save string identifier, wait for command to save results ------


    //-----------handle error in transmission: no result at all-----------
    uint16_t answerSum = 0;
    for (uint8_t i=0; i< NUM_SATELLITES; i++)
      if (answers[i].length()) answerSum++;
    if (answerSum == 0) 
    {
      SaveToFile = false;
      M5.Lcd.setTextSize(2);
      M5.Lcd.setTextColor(TFT_RED, TFT_BLACK);
      M5.Lcd.println("nothing received");
      M5.Lcd.setTextColor(TFT_WHITE, TFT_BLACK);
      TftReset = true;
      delay(1500);
    }
    //-----------END handle error in transmission: no result at all-----------
    ClampsOnly = false;
  }  //end button C, measurement button


    //-----------save result to SD card-----------
  if (SaveToFile)  //something was received
  {
    if (Saved == true) 
    {
      M5.Lcd.fillScreen(TFT_BLACK);
      M5.Lcd.setCursor(0, 0);
      M5.Lcd.setTextSize(2);
      M5.Lcd.setTextColor(TFT_RED, TFT_BLACK);
      M5.Lcd.println("Error:");
      M5.Lcd.println("saved already!");
      M5.Lcd.setTextColor(TFT_WHITE, TFT_BLACK);
    }
    else
    {
      MyFile = SD.open("/AA_log.txt", FILE_APPEND);
      if (FirstTime)
      {
        MyFile.print("time stamp;string;");  //start of header line
        for (uint8_t i=0; i< NUM_SATELLITES; i++)
        {
          MyFile.print(satellites[i]); //write identifier for each result
          MyFile.print(";"); 
          if (satellites[i] == "irr_1") MyFile.print("temp_1;temp_2;");       
        }
        FirstTime = false;
        MyFile.println();  //end of header line
      }
      //print timestamp
      char tempString[20];
      sprintf(tempString, "%02d.%02d.%04d %02d:%02d", Now.day(), Now.month(), Now.year(), Now.hour(), Now.minute());
      MyFile.print(tempString); MyFile.print(";");
      MyFile.print(StringID); MyFile.print(";");
      for (uint8_t i=0; i< NUM_SATELLITES; i++)
      {
        if (answers[i].length()>1)
         {
            MyFile.print(answers[i]);
         }
        else
        {
          if (satellites[i] == "irr_1") MyFile.print(";;;"); 
          else MyFile.print(";");
        }
      }
      MyFile.println();
      Saved = true;
      M5.Lcd.setTextSize(2);
      M5.Lcd.println("saved!");
      MyFile.close();
      if(GlobalClient != NULL && GlobalClient->status() == WS_CONNECTED)   //feedback to web page client: file saved
      {
        GlobalClient->text("SAVED");
      }
    } //end else
    delay(500); //otherwise cycles too quickly
    SaveToFile = false;
    TftReset = true;
  }
  //END -----------save result to SD card-----------
} //end main loop

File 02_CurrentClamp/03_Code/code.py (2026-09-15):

# Radio signal "ME"ASURE or "CL"AMPS triggers 10x ADC measurements (averaged)
import time
import board
import busio
import adafruit_ads1x15.ads1115 as ADS
import digitalio
import adafruit_rfm9x
from adafruit_ads1x15.analog_in import AnalogIn
RADIO_FREQ_MHZ = 433.0  # Frequency of the radio in Mhz. Must match your
i2c = busio.I2C(board.SCL, board.SDA)

# clamp 10 -> clamp_0  
CLAMP = "clamp_0"
NODENR = int(CLAMP[-1])
if NODENR == 0:
  NODENR = 10

# Define pins connected to the chip
CS = digitalio.DigitalInOut(board.A4)
RESET = digitalio.DigitalInOut(board.A3)
# Initialize SPI bus.
spi = busio.SPI(board.SCK, MOSI=board.MOSI, MISO=board.MISO)
# Create the ADC object using the I2C bus
ads = ADS.ADS1115(i2c, gain=2/3)

# Initialze RFM radio
rfm9x = adafruit_rfm9x.RFM9x(spi, CS, RESET, RADIO_FREQ_MHZ)
rfm9x.tx_power = 23
rfm9x.signal_bandwidth = 62500
rfm9x.coding_rate = 8
rfm9x.spreading_factor = 9
rfm9x.enable_crc = True
# ADC differential reading between P0 and P1
chan = AnalogIn(ads, ADS.P0, ADS.P1)

while True:
    ads = ADS.ADS1115(i2c, gain=2/3)
    packet = rfm9x.receive(with_header=True,timeout=2)
    if packet is not None:
        try:
          packetText = str(packet, 'ascii')
        except:
          packetText = ""
        print(packetText)
        if ((packetText.find("ME") > -1) or (packetText.find("CL") > -1)):
            startTime = time.monotonic()   # start time after reception
            rfm9x.idle();  # enter radio idle mode
            firstReading = abs(chan.voltage)
            if (firstReading < 0.225):
              ads = ADS.ADS1115(i2c, gain=16)
            elif (firstReading < 0.45):
              ads = ADS.ADS1115(i2c, gain=8)
            elif (firstReading < 0.975):
              ads = ADS.ADS1115(i2c, gain=4)
            elif (firstReading < 1.95):
              ads = ADS.ADS1115(i2c, gain=2)
            elif (firstReading < 3.975):
              ads = ADS.ADS1115(i2c, gain=1)
            j = 0
            reference = abs(chan.voltage)
            refMin = 0.95 * reference   # for outlier identification
            refMax = 1.05 * reference   # for outlier identification
            sumVoltage = 0
            for i in range(0, 10):
              readVolt = abs(chan.voltage)
              readValue = chan.value
              if ((readValue < 0xFFFA) and (readVolt < refMax) and (readVolt > refMin)):
                sumVoltage += readVolt
                j += 1
            outText = CLAMP+';'  # prepare output text
            if (j == 0):  # overshoot in all 10 voltage readings
              outText += "ERROR"+';'
            else:
              outText += "{:>5.4f}".format(sumVoltage/j*10.0)+';'
            waitTime = NODENR * 0.8  # 0.8s for each clamp before, 0.8s initially for repeater
            waitTime += startTime - time.monotonic()
            if (ord(packetText[1]) == 13): #message from repeater, ~350 ms delayed
              waitTime -= 0.35
            if (waitTime > 0):
              time.sleep(waitTime)
            rfm9x.send(outText, node=NODENR)

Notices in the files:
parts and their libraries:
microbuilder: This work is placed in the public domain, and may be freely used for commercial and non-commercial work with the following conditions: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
